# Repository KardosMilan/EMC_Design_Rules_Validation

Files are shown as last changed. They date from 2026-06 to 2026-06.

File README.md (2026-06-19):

# Automotive SEPIC Converter — EMC Design Rules Validation

> **Complete engineering workflow for an automotive-grade SEPIC DC-DC converter, from power-stage dimensioning through iterative EMC filter development to laboratory validation.**

---

## Overview

This project documents the full development and validation cycle of a switching power supply designed to meet demanding automotive EMC requirements. Starting from topology selection and component dimensioning, the work progresses through multiple hardware revisions, EMC-oriented filter design, and systematic laboratory validation — including electrical, frequency-domain, and thermal measurements.

Two contrasting PCB design iterations (SEPIC-A2 and SEPIC-B) are included side by side, demonstrating the measurable EMC impact of layout and filter decisions.

## Example of a designed PCB in aluminium housing

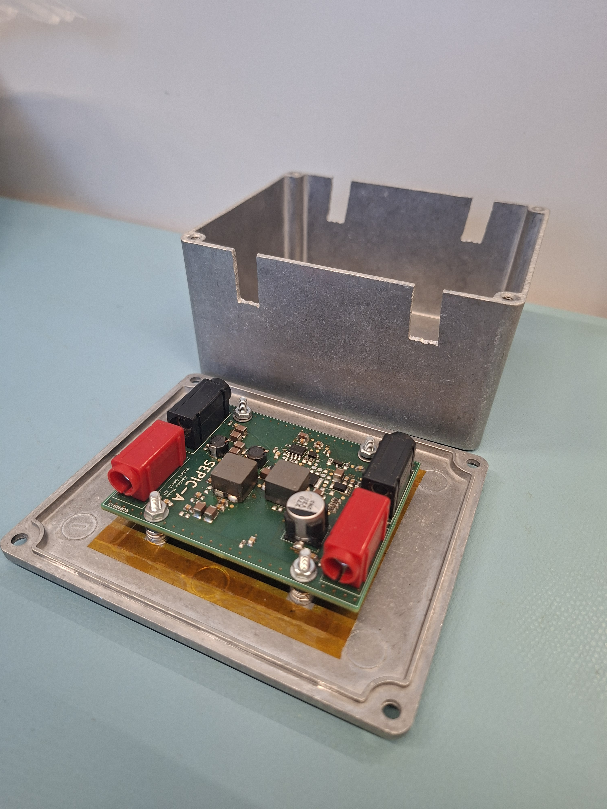
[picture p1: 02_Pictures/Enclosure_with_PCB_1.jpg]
Enclosure with PCB


---

## Project Goals

- Design an automotive SEPIC converter power stage with appropriate switching-frequency selection and thermal management
- Identify and characterise conducted and radiated emission sources
- Develop and iteratively optimise LC input/output EMC filters
- Validate all design decisions through laboratory measurements
- Correlate theoretical calculations with experimental results
- Produce a documented engineering process suitable for future design iterations

---

## Engineering Workflow

### 1 — System Design
Component selection, power-stage dimensioning, switching-frequency optimisation, thermal considerations, and initial PCB layout preparation.

### 2 — EMC Filter Development
LC filter calculations, topology comparison, resonance analysis, and iterative optimisation verified against laboratory measurements. All calculation sheets are included in the repository.

### 3 — Prototype Manufacturing
Custom PCB design with microcontroller integration, automotive-grade components, and dedicated measurement interfaces. Two hardware revisions are provided:

| Revision | Design Intent |
|---|---|
| **SEPIC-A2** | Reference iteration — poor EMC layout (emission source example) |
| **SEPIC-B**  | Optimised iteration — improved EMC layout and filter (target design) |

### 4 — Measurement & Validation

| Domain | Method |
|---|---|
| Electrical  | Switching waveform analysis, frequency-domain characterisation, noise quantification |
| EMC | Conducted emission measurement, filter effectiveness comparison between revisions |
| Thermal | FLIR thermal imaging, hotspot identification, thermal performance validation |
| Correlation | Calculated vs. measured comparison across all key parameters |

---

## Repository Structure

```
EMC_Design_Rules_Validation/
├── 01_Documents/
│   ├── Filter design documentation
│   ├── Measurement plans
│   ├── Correlation calculations
│   ├── Thermal analysis results
│   └── Oscilloscope captures
│
├── 02_Pictures/
│   ├── Prototype photos
│   └── Laboratory setup
│
├── 03_Calculations/
│   ├── Design calculations
│   ├── EMC filter calculations
│   └── Validation worksheets
│
├── 04_SEPIC_microcontroller_prototype/
│   ├── Prototype hardware
│   ├── Embedded controller integration
│   └── Supporting component libraries
│
└── 05_HW_design/
    ├── SEPIC-A2/     ← bad EMC design example
    ├── SEPIC-B/      ← optimised EMC design example
    └── PCB design resources
```

---

## Technology Stack

| Area | Tools & Methods |
|---|---|
| PCB Design | CAD schematic & layout tools |
| Calculations | Excel-based engineering worksheets |
| Electrical Measurement | Oscilloscope (time & frequency domain)  |
| Thermal Measurement | FLIR thermal camera |
| EMC Measurement | Conducted emission laboratory equipment |
| Embedded Platform | Automotive-grade microcontroller |

---

## Key Outcomes

- Designed and validated two SEPIC converter hardware revisions with measurably different EMC behaviour
- Developed EMC filter solutions grounded in both analytical calculation and experimental iteration
- Demonstrated a systematic correlation methodology between design predictions and laboratory results
- Produced a complete, reproducible engineering workflow applicable to future power electronics and EMC projects

---

## Author

**Kardos Milan**  
Electrical / Electronics Engineer  
*Specialising in Power Electronics, EMC Validation, Hardware Design, and Embedded Systems*

---

## License

This repository is shared for portfolio and reference purposes. All rights reserved.

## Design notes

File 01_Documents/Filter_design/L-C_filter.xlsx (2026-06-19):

Power supply input impedance |  |  | fi | s_i | Z_i
 |  |  | 0 | 0 | 23.87826319
V_in | 40 | V | 1 | 0.5711986643 | 28445.95364
I_out | 1 | A | 2 | 12.56637061 | 2550600.543
V_out | 5 | V | 3 | 18.84955592 | 276482.7453
 |  |  | 4 | 25.13274123 | 5410530.956
Output inductor |  |  |  | 0 | 23.87826319
L_out | 66 | uH |  | 0 | 23.87826319
 |  |  |  | 0 | 23.87826319
DC resistance |  |  |  | 0 | 23.87826319
R_L | 0.0088 | Ohm |  | 9 | 863306.2534
 |  |  |  | 10 | 93938.80675
Output capacitor |  |  |  | 11 | 18134.86307
C_out | 68 | uF |  | 12 | 3941.037132
ESR_C_out | 0.09 | Ohm |  | 13 | 2651674.45
 |  |  |  | 14 | 2885210.735
Duty Cycle | 0.458 | - |  | 15 | 3119283.552
 |  |  |  | 16 | 3353804.378
Output Impedance |  |  |  | 17 | 3588703.15
R_out | 5 | Ohm |  | 18
f_i | 100 | Hz |  | 19
w_i | 628 |  |  | 20
s_i | 3945.840373 |  |  | 21
Z_i |  |  |  | 22
 |  |  |  | 23
 |  |  |  | 24
 |  |  |  | 25
 |  |  |  | 26
 |  |  |  | 27
 |  |  |  | 28
 |  |  |  | 29
 |  |  |  | 30
 |  |  |  | 31
Filter
L_f
C_f
R_d | #DIV/0!
C_d | 0
ESR_Cd
Z_3 | #DIV/0!
Z_2
Z_3-2 | #DIV/0!
F_2 | #DIV/0!
Z_f2
Z_1

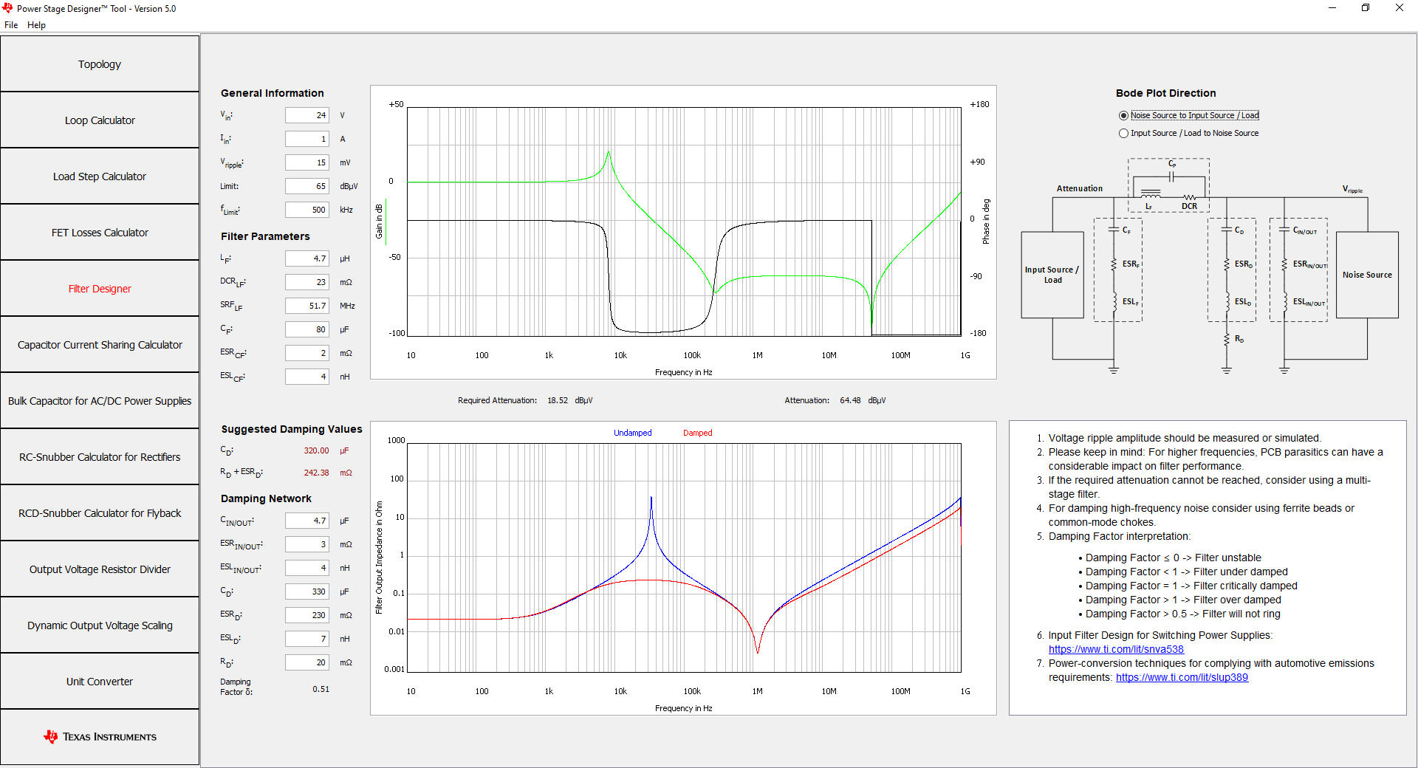
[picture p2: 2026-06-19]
01_Documents/Filter_design/Final_Filter3.png

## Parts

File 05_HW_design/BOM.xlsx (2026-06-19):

Reference | Value | Shop | Datasheet | Footprint | Qty | Bolti Darab | Ár (ft) | Összesen |  | 4db PCB-re [db] | Összesen [ft]
R5 | 1.1k | https://hu.farnell.com/panasonic/erj6geyj112v/res-1k1-5-0-125w-0805-thick-film/dp/2323808 | http://industrial.panasonic.com/cdbs/www-data/pdf/RDA0000/AOA0000C301.pdf | Resistor_SMD:R_0805_2012Metric_Pad1.20x1.40mm_HandSolder | 1 | 10 | 14.7 | 147 |  | 4 | 147
R4 | 1R | https://hu.farnell.com/bourns/cr0805-j-1r0elf/res-1r-5-0-125w-0805-thick-film/dp/2333534 | https://www.farnell.com/datasheets/3693949.pdf | Resistor_SMD:R_0805_2012Metric_Pad1.20x1.40mm_HandSolder | 1 | 10 | 3.6 | 36 |  | 4 | 36
R28 | R | https://hu.farnell.com/walsin/wr12x151-jtl/res-150r-5-0-25w-1206-thick-film/dp/2671138 | https://4donline.ihs.com/images/VipMasterIC/IC/WATC/WATC-S-A0005256878/WATC-S-A0005256878-1.pdf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 | Resistor_SMD:R_1206_3216Metric_Pad1.30x1.75mm_HandSolder | 1 | 10 | 5.571 | 55.71 |  | 4 | 55.71
C31 | 1uF, 25V | https://hu.farnell.com/avx/08053g105zat2a/cap-1-f-25v-y5v-0805/dp/2332746 | https://4donline.ihs.com/images/VipMasterIC/IC/AVXC/AVXC-S-A0011272541/AVXC-S-A0011272541-1.pdf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 | Capacitor_SMD:C_0805_2012Metric_Pad1.18x1.45mm_HandSolder | 1 | 10 | 42.88 | 428.8 |  | 4 | 428.8
C32 | 680pF, 100V | https://hu.farnell.com/avx/06031c681kat2a/cap-680pf-100v-mlcc-0603/dp/3288880 | https://4donline.ihs.com/images/VipMasterIC/IC/AVXC/AVXC-S-A0013335498/AVXC-S-A0014059611-1.pdf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 | Capacitor_SMD:C_0603_1608Metric_Pad1.08x0.95mm_HandSolder | 1 | 10 | 18 | 180 |  | 4 | 180
C5,C6,C7,C8,C9,C14,C15,C16,C17,C18,C20,C42 | 10uF, 50V | https://hu.farnell.com/tdk/cga6p3x7s1h106k250ab/cap-10-f-50v-10-x7s-1210/dp/2211159 | https://www.farnell.com/datasheets/3816851.pdf | Capacitor_SMD:C_1210_3225Metric_Pad1.33x2.70mm_HandSolder | 12 | 12 | 244.47 | 2933.64 |  | 48 | 11734.56
C4,C10,C11,C12,C13,C19,C41 | 100nF, 50V | https://hu.farnell.com/kemet/c0805x104j5rac3316/cap-0-1-f-50v-5-x7r-0805/dp/2666904 | https://4donline.ihs.com/images/VipMasterIC/IC/KEME/KEME-S-A0018777717/KEME-S-A0018891838-1.pdf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 | Capacitor_SMD:C_0805_2012Metric_Pad1.18x1.45mm_HandSolder | 7 | 10 | 293 | 2930 |  | 28 | 8204
C1,C2,C3,C21,C23,C37,C38,C46 | 1nF, 100V | https://hu.farnell.com/kemet/c0805x102k1racauto/cap-1000pf-100v-10-x7r-0805/dp/2821055 | https://4donline.ihs.com/images/VipMasterIC/IC/KEME/KEME-S-A0018892237/KEME-S-A0018892237-1.pdf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 | Capacitor_SMD:C_0805_2012Metric_Pad1.18x1.45mm_HandSolder | 8 | 10 | 84 | 840 |  | 32 | 2688
C47 | 2.2uF, 50V | https://hu.farnell.com/kemet/c1206c225m5ractu/cap-2-2-f-50v-20-x7r-1206/dp/2820946 | https://search.kemet.com/component-documentation/download/specsheet/C1206C225M5RACTU | Capacitor_SMD:C_1206_3216Metric_Pad1.33x1.80mm_HandSolder | 1 | 10 | 89 | 890 |  | 4 | 890
C22 | 470pF, 50V | https://hu.farnell.com/kemet/c0603s471k5racauto/cap-mlcc-aec-q200-470pf-50v-0603/dp/2904848 | https://4donline.ihs.com/images/VipMasterIC/IC/KEME/KEME-S-A0018897373/KEME-S-A0018902451-1.pdf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 | Capacitor_SMD:C_0603_1608Metric_Pad1.08x0.95mm_HandSolder | 1 | 10 | 75 | 750 |  | 4 | 750
C30 | 100pF, 50V | https://hu.farnell.com/kemet/c0402c101k5gacauto/cap-100pf-50v-10-c0g-np0-0402/dp/2904514 | https://4donline.ihs.com/images/VipMasterIC/IC/KEME/KEME-S-A0018897402/KEME-S-A0018897402-1.pdf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 | Capacitor_SMD:C_0402_1005Metric_Pad0.74x0.62mm_HandSolder | 1 | 10 | 14 | 140 |  | 4 | 140
C29 | 1nF, 50V | https://hu.farnell.com/kemet/c0402c102j5racauto/cap-1000pf-50v-5-x7r-0402/dp/2904523 | https://4donline.ihs.com/images/VipMasterIC/IC/KEME/KEME-S-A0018897413/KEME-S-A0018897413-1.pdf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 | Capacitor_SMD:C_0402_1005Metric | 1 | 10 | 16 | 160 |  | 4 | 160
C34,C35,C36,C43 | 4.7nF, 100V | https://hu.farnell.com/kemet/c0805c472k1ractu/cap-4700pf-100v-10-x7r-0805/dp/2332407 | https://4donline.ihs.com/images/VipMasterIC/IC/KEME/KEME-S-A0018902345/KEME-S-A0018902501-1.pdf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 | Capacitor_SMD:C_0805_2012Metric_Pad1.18x1.45mm_HandSolder | 4 | 10 | 57 | 570 |  | 16 | 912
D1,D2 | PMEG6030ELP | https://hu.farnell.com/nexperia/pmeg6030elpx/schottky-rect-3a-60v-sod128/dp/2498564 | https://4donline.ihs.com/images/VipMasterIC/IC/NEXP/NEXP-S-A0003105620/NEXP-S-A0003105670-1.pdf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 | Diode_SMD:D_SOD-128 | 2 | 5 | 192 | 960 |  | 8 | 1536
U2 | SZBZX84C4V7ET1G | https://hu.farnell.com/on-semiconductor/szbzx84c4v7et1g/zener-diode-aecq101-4-7v-0-25w/dp/3368153 | https://4donline.ihs.com/images/VipMasterIC/IC/ONSM/ONSM-S-A0004900107/ONSM-S-A0002809067-1.pdf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 | Package_TO_SOT_SMD:SOT-23 | 1 | 5 | 98.5 | 492.5 |  | 4 | 492.5
R9 | 5.62k | https://hu.farnell.com/panasonic/erj2rkf5621x/res-5k62-1-0-1w-0402-thick-film/dp/2302714 | https://4donline.ihs.com/images/VipMasterIC/IC/PANA/PANA-S-A0007945459/PANA-S-A0007945459-1.pdf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 | Resistor_SMD:R_0402_1005Metric_Pad0.72x0.64mm_HandSolder | 1 | 10 | 10.5 | 105 |  | 4 | 105
R6,R18,R19,R26 | 22R | https://hu.farnell.com/multicomp-pro/mp000064/res-aec-q200-22r-5-0-25w-0805/dp/3127834 | https://4donline.ihs.com/images/VipMasterIC/IC/SCMP/SCMP-S-A0008596024/SCMP-S-A0008596024-1.pdf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 | Resistor_SMD:R_0805_2012Metric_Pad1.20x1.40mm_HandSolder | 4 | 10 | 23.44 | 234.4 |  | 16 | 375.04
R23 | 0.05R | https://hu.farnell.com/multicomp-pro/mclrp12jtdrr050/res-detec-corriente-0r05-5-3w/dp/2828309 | https://4donline.ihs.com/images/VipMasterIC/IC/SCMP/SCMP-S-A0011506898/SCMP-S-A0011506898-1.pdf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 | Resistor_SMD:R_2512_6332Metric_Pad1.40x3.35mm_HandSolder | 6 | 10 | 133.4 | 1334 |  | 24 | 3201.6
Q1 | BUK9Y25-60E_A004X | https://hu.farnell.com/nexperia/buk9y25-60e-115/mosfet-aecq101-n-ch-60v-34a-lfpak56/dp/3439716 | https://assets.nexperia.com/documents/data-sheet/BUK9Y25-60E.pdf | KiCad1:BUK9Y2560EA004X | 1 | 1 | 345 | 345 |  | 4 | 1380
D3 | PMEG6020ELR | https://hu.farnell.com/nexperia/pmeg6020elrx/rectifier-schottky-2a-60v-sod/dp/2469682 | https://assets.nexperia.com/documents/data-sheet/PMEG6020ELR.pdf | Diode_SMD:Nexperia_CFP3_SOD-123W | 1 | 5 | 187.9 | 939.5 |  | 4 | 939.5
C26 | 270 uF, 35V | https://at.farnell.com/en-AT/epcos/b40900b7277m000/cap-270uf-35v-alu-elec-hybrid/dp/3266927 | https://product.tdk.com/system/files/dam/doc/product/capacitor/aluminum-electrolytic/hybrid-polymer/data_sheet/20/30/db/aec/b40900.pdf | Capacitor_SMD:CP_Elec_10x10.5 | 1 | Itthon nem elérhet? csak 1000 darabos |  |  | euroban lehet csak | 4
C40 | 330pF, 100V | https://hu.farnell.com/kemet/c0402c331j1gactu/cap-330pf-100v-mlcc-0402/dp/2940861 | https://search.kemet.com/component-documentation/download/specsheet/C0402C331J1GACTU | Capacitor_SMD:C_0402_1005Metric_Pad0.74x0.62mm_HandSolder | 1 | 10 | 29.3 | 293 |  | 4 | 293
C44 | 47nF, 16V | https://hu.farnell.com/yageo/cc0402krx7r7bb472/cap-4700pf-16v-10-x7r-0402/dp/3019251 | https://www.yageo.com/upload/media/product/productsearch/datasheet/mlcc/UPY-GPHC_X7R_6.3V-to-50V_20.pdf | Capacitor_SMD:C_0402_1005Metric_Pad0.74x0.62mm_HandSolder | 1 | 10 | 5.7 | 57 |  | 4 | 57
C25 | 100nF, 50V | https://hu.farnell.com/kemet/c0805x104j5rac3316/cap-0-1-f-50v-5-x7r-0805/dp/2666904 | https://search.kemet.com/component-documentation/download/specsheet/C0805X104J5RAC3316 | Capacitor_SMD:C_0805_2012Metric_Pad1.18x1.45mm_HandSolder | 1 | 10 | 293.3 | 2933 |  | 4 | 2933
C39 | 4.7nF, 50V | https://hu.farnell.com/kemet/c1206c475k5pactu/cap-4-7-f-50v-10-x5r-1206/dp/1572637 | https://search.kemet.com/component-documentation/download/specsheet/C0805X104J5RAC3316 | Capacitor_SMD:C_1206_3216Metric_Pad1.33x1.80mm_HandSolder | 1 | 10 | 85.3 | 853 |  | 4 | 853
L3,L4 | VCSC108T-150MS6K | https://www.digikey.de/de/products/detail/delta-electronics-cyntec/VCSC108T-150MS6K/22581627 | https://www.cyntec.com/upfile/products/download/(A8)%20VCSC108T%20MS6K%20Series_standard.pdf | Inductor_SMD:VCSC108T | 2 | 2 | 900 | 1800 | euroban lehet csak | 8
L1,L2 | 4.7uH | https://hu.farnell.com/tdk/clf6045t-4r7n-d/inductor-4-7uh-2-5a-30-pwr-100khz/dp/2362560 | https://www.farnell.com/datasheets/1763485.pdf | KiCad5:CLF6045__ | 2 | Ithon csak 1000 darabos |  |  |  | 8
R25 | 5.11k | https://hu.farnell.com/walsin/wr08x5111ftl/res-5k11-1-0-125w-0805-thick-film/dp/2671054 | https://4donline.ihs.com/images/VipMasterIC/IC/WATC/WATC-S-A0005256878/WATC-S-A0005256878-1.pdf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 | Resistor_SMD:R_0805_2012Metric_Pad1.20x1.40mm_HandSolder | 1 | 10 | 10 | 100 |  | 4 | 100
R11,R12,R21,R22 | 2.2R | https://hu.farnell.com/te-connectivity/crgcq0603j2r2/res-2r2-5-0603-thick-film/dp/2861848 | https://www.farnell.com/datasheets/2609223.pdf | Resistor_SMD:R_0201_0603Metric_Pad0.64x0.40mm_HandSolder | 4 | 10 | 5.17 | 51.7 |  | 16 | 82.72
R7 | 15k | https://hu.farnell.com/multicomp/mcmr04x153-jtl/res-15k-5-0-0625w-0402-ceramic/dp/2072651 | https://www.farnell.com/datasheets/2860635.pdf | Resistor_SMD:R_0402_1005Metric_Pad0.72x0.64mm_HandSolder | 1 | 10 | 2.8 | 28 |  | 4 | 28
R8 | 46.4k | https://hu.farnell.com/multicomp-pro/mcwf08w4642btl/res-46k4-0-1-0-125w-0805-thin/dp/2338193 | https://www.farnell.com/datasheets/2863884.pdf | Resistor_SMD:R_0805_2012Metric_Pad1.20x1.40mm_HandSolder | 1 | 10 | 121.4 | 1214 |  | 4 | 1214
J1 | Banana_Red_IN | https://hu.farnell.com/multicomp/24-243-1/banana-socket-20a-4mm-pcb-red/dp/1698982?pf_custSiteRedirect=true | https://www.farnell.com/datasheets/2963540.pdf | banana_red:242431 | 1 | 1 | 319 | 319 |  | 4 | 1276
J2 | Banana_Red_OUT | https://hu.farnell.com/multicomp/24-243-1/banana-socket-20a-4mm-pcb-red/dp/1698982?pf_custSiteRedirect=true | https://www.farnell.com/datasheets/2963540.pdf | banana_red:242431 | 1 | 1 | 319 | 319 |  | 4 | 1276
J3 | Banana_Black_IN | https://hu.farnell.com/multicomp/24-243-2/receptacle-20a-4mm-pcb-solder/dp/1698983?pf_custSiteRedirect=true | https://www.farnell.com/datasheets/2963540.pdf | banana_black:242432 | 1 | 1 | 319 | 319 |  | 4 | 1276
J4 | Banana_Black_OUT | https://hu.farnell.com/multicomp/24-243-2/receptacle-20a-4mm-pcb-solder/dp/1698983?pf_custSiteRedirect=true | https://www.farnell.com/datasheets/2963540.pdf | banana_black:242432 | 1 | 1 | 319 | 319 |  | 4 | 1276
R1,R2,R3 | 21.5R | https://hu.farnell.com/te-connectivity/rp73pf2a21r5btdf/res-21r5-0-1-0-25w-0805-thin-film/dp/2116983 | https://www.farnell.com/datasheets/3156821.pdf | Resistor_SMD:R_0805_2012Metric_Pad1.20x1.40mm_HandSolder | 3 | 3 | 113 | 339 |  | 12 | 1356
R17 | 5.11R | https://hu.farnell.com/yageo/rc0805fr-075r11l/res-5r11-1-0-125w-0805-thick-film/dp/3496079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 | https://www.farnell.com/datasheets/3795017.pdf | Capacitor_SMD:C_0805_2012Metric_Pad1.18x1.45mm_HandSolder | 1 | 10 | 11 | 110 |  | 4 | 110
C24 | 10uF, 50V | https://hu.farnell.com/tdk/cga6p3x7s1h106k250ab/cap-10-f-50v-10-x7s-1210/dp/2211159 | https://www.farnell.com/datasheets/3816851.pdf | Capacitor_SMD:C_1210_3225Metric_Pad1.33x2.70mm_HandSolder | 1 | 1 | 244 | 244 |  | 4 | 976
C27,C28 | 2.2uF, 50V | https://hu.farnell.com/tdk/c3216x7r1h225k160ae/cap-2-2-f-50v-10-x7r-1206/dp/2906842 | https://www.farnell.com/datasheets/3919271.pdf | Capacitor_SMD:C_1206_3216Metric_Pad1.33x1.80mm_HandSolder | 2 | 5 | 163 | 815 |  | 8 | 1304
R10 | 3.01k | https://hu.farnell.com/koa-speer-electronics/rk73h1ettp3011f/res-3k01-1-0-1w-0402/dp/3538958 | https://www.koaglobal.com/-/media/Files/KOA_Global/EN/product/commonpdf/rk73h.pdf | Resistor_SMD:R_0402_1005Metric_Pad0.72x0.64mm_HandSolder | 1 | 10 | 6 | 60 |  | 4 | 60
IC1 | NCV898031D1R2G | https://hu.farnell.com/on-semiconductor/ncv898031d1r2g/dc-dc-controllers/dp/3613065 | https://www.onsemi.com/pub/Collateral/NCV898031-D.PDF?hkey=EF798316E3902B6ED9A73243A3159BB0 | KiCad4:SOIC127P600X175-8N | 1 | 2500 dbos szalag |  |  |  | 4
C33 | 6.8nF, 100V | https://hu.farnell.com/wurth-elektronik/885012206113/cap-6800pf-100v-10-x7r-0603/dp/2812367 | https://www.we-online.com/components/products/datasheet/885012206113.pdf | Capacitor_SMD:C_0603_1608Metric_Pad1.08x0.95mm_HandSolder | 1 | 10 | 10.4 | 104 |  | 4 | 104
R24 | 10k | https://hu.farnell.com/yageo/rt0805brb0710kl/res-10k-0-1-0-125w-0805-thin-film/dp/3496710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 | https://www.yageo.com/upload/media/product/app/datasheet/rchip/pyu-rt_1-to-0.01_rohs_l.pdf | Resistor_SMD:R_0805_2012Metric_Pad1.20x1.40mm_HandSolder | 1 | 10 | 135 | 1350 |  | 4 | 1350
 |  |  |  |  |  | Összesen: |  | 26099.25 |  |  | 50280.43
Housing | 4628 | https://hu.farnell.com/hammond/1590ce/enclosure-diecast/dp/1877076 | https://www.farnell.com/datasheets/1913809.pdf | .
 |  | EURO/DB | DB | össz
PCB rendelés | 73200 | 183 | 4 | 292800
 | https://www.eurocircuits.hu/pcb-beultetes-standard-pool/
 | https://be.eurocircuits.com/shop/assembly/configurator.aspx?sessionid=cbd32a67-34b7-461b-924a-d88c2fe45909 |  |  |  |  | Végösszeg | 347708.43

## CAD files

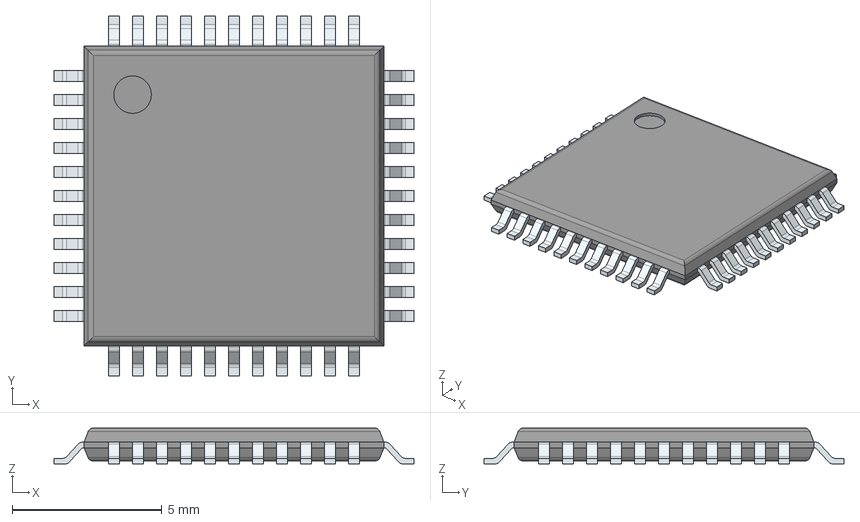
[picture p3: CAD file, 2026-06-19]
04_SEPIC_microcontroller_prototype/MYLIB/LIB_ATMEGA32U4-AU/ATMEGA32U4-AU/3D/ATMEGA32U4-AU.stp
12.0 x 12.0 x 1.20 mm
PinsArrayLR
PinsArrayTB

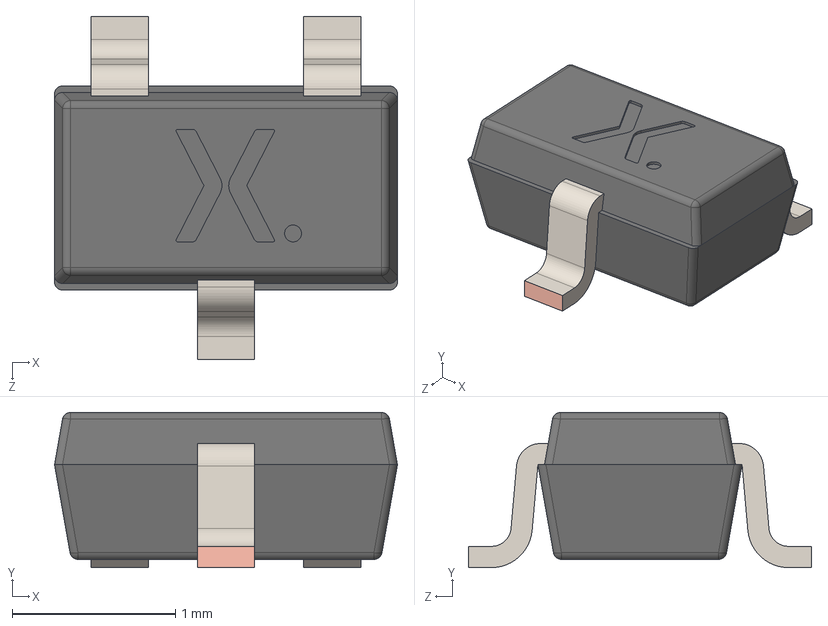
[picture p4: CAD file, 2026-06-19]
04_SEPIC_microcontroller_prototype/MYLIB/LIB_BC846BW,115/BC846BW,115/3D/BC846BW,115.stp
2.10 x 0.95 x 2.10 mm
Upper body
lower body
Lead x 3

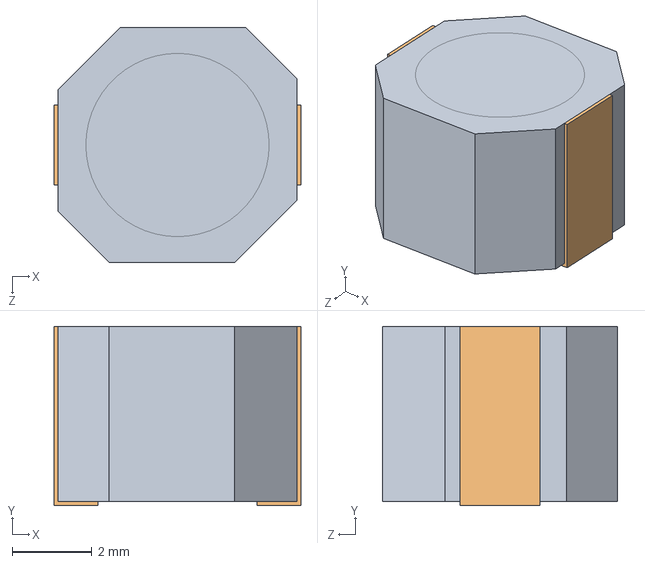
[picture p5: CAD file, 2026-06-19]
04_SEPIC_microcontroller_prototype/MYLIB/LIB_CLF6045T-4R7N-D/CLF6045T-4R7N-D/3D/CLF6045T-4R7N-D.stp
6.20 x 4.50 x 5.90 mm
CLF6045素体
CLF6045端子 x 2

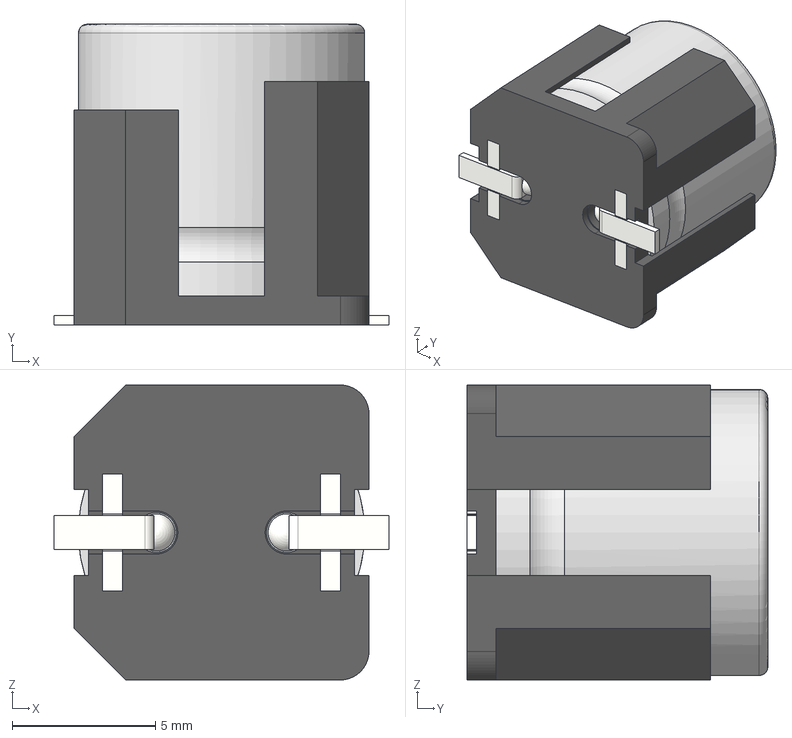
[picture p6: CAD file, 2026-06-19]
04_SEPIC_microcontroller_prototype/MYLIB/LIB_EEHZC1V271V/EEHZC1V271V/3D/EEHZC1V271V.stp
11.7 x 10.5 x 10.3 mm
ケースΦ10x9.5L SIDE CODE G
耐振品座版Φ10 SIZE CODE G
耐振品座版用補助端子Φ10 SIZE CODE G x 2
耐振品リード線Φ10 SIZE CODE G x 2

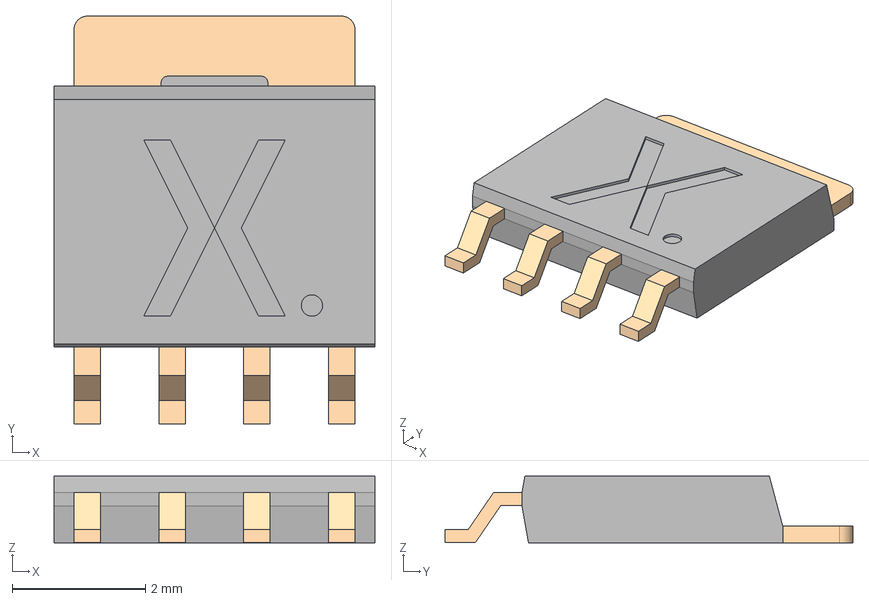
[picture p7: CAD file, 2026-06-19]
04_SEPIC_microcontroller_prototype/MYLIB/LIB_PHPT60415NYX/PHPT60415NYX/3D/PHPT60415NYX.stp
4.81 x 6.11 x 0.998 mm

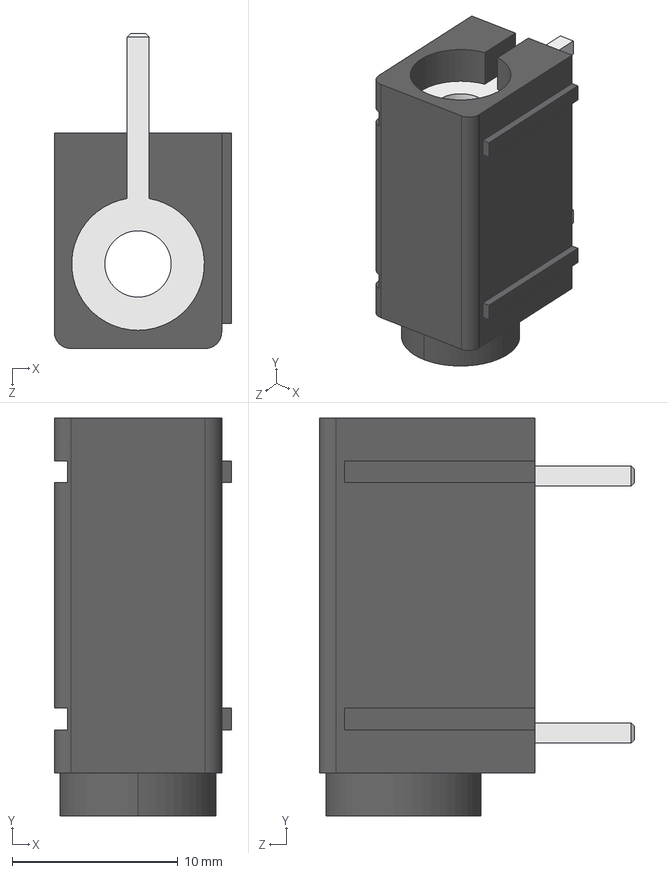
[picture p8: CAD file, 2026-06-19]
05_HW_design/SEPIC-A2/MYLIB/LIB_24.243.Black/24.243.2/3D/24.243.2.stp
10.7 x 24.0 x 19.0 mm

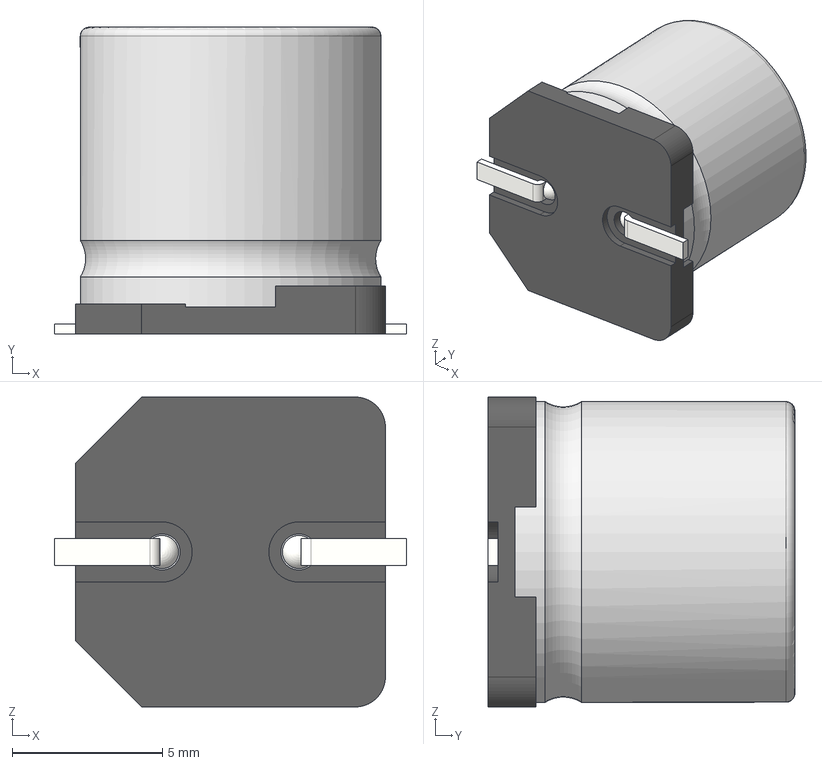
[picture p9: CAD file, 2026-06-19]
05_HW_design/SEPIC-B/MYLIB/LIB_EEEFT1H331GP/EEEFT1H331GP/3D/EEEFT1H331GP.stp
11.7 x 10.2 x 10.3 mm
標準品ケースΦ10x9.3L SIDE CODE G
標準品座版Φ10 SIZE CODE G
標準品リード線Φ10 SIZE CODE G改 x 2

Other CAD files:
05_HW_design/SEPIC-A2/MYLIB/LIB_24.243.Red/24.243.1/3D/24.243.1.stp
05_HW_design/SEPIC-B/MYLIB/LIB_24.243.Red/24.243.1/3D/24.243.1.stp
04_SEPIC_microcontroller_prototype/MYLIB/LIB_629105150521/629105150521/3D/629105150521.stp
04_SEPIC_microcontroller_prototype/MYLIB/LIB_629105150521/629105150521/Allegro/629105150521.psm
04_SEPIC_microcontroller_prototype/MYLIB/LIB_629105150521/629105150521/DEHDL/629105150521/chips/chips.prt
04_SEPIC_microcontroller_prototype/MYLIB/LIB_ATMEGA32U4-AU/ATMEGA32U4-AU/Allegro/qfp80p1200x1200x120-44n.psm
04_SEPIC_microcontroller_prototype/MYLIB/LIB_ATMEGA32U4-AU/ATMEGA32U4-AU/DEHDL/atmega32u4_au/chips/chips.prt
04_SEPIC_microcontroller_prototype/MYLIB/LIB_BC846BW,115/BC846BW,115/Allegro/sot65p210x110-3n.psm
04_SEPIC_microcontroller_prototype/MYLIB/LIB_BC846BW,115/BC846BW,115/DEHDL/bc846bw_115/chips/chips.prt
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

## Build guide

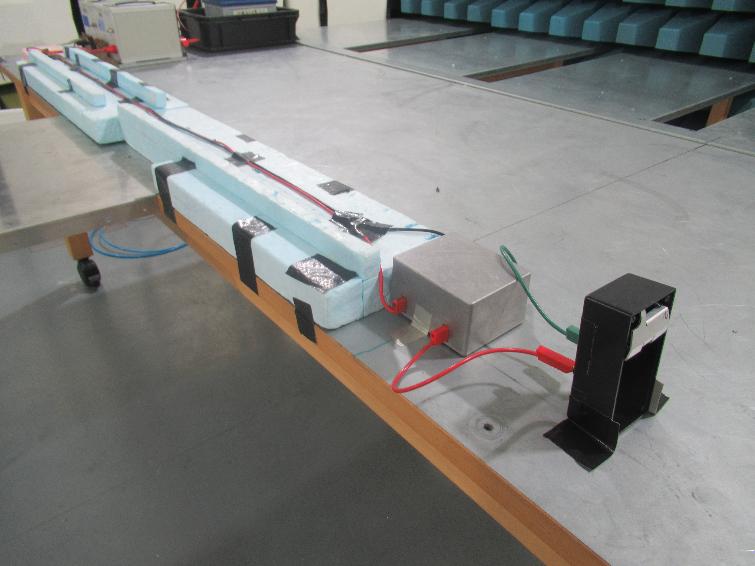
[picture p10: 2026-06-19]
01_Documents/MEASUREMENTS/REA_measurement_setup/IMG_0643.JPG

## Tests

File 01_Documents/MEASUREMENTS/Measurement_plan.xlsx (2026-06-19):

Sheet: REA
Mode | NH | No housing |  |  | követelmény? | CEV csütörtök
 | HO | Housing |  |  | 30MHz alatt RBW 9kHz |  |  | 13,5 V | 5 Amperes áramkorlát
 | GH | Grounded housing |  |  | felette 120kHz
 |  |  |  |  | illetve Average és peak detector a teljes sávban egy-két sávban pedig QP detektor még érdekes lehet po AM és FM sáv
MAKE PICTURES!!!
Meas. Number | SETUP | DUT | Mode | Polarization | Frequency | Antenna | Status
01 | Setup 1 | SEPIC-A | NH | V | 9 kHz-30 MHz | Monopole | Done
02 | Setup 1 | SEPIC-A | NH | H | 30 MHz - 1GHz | Bilog | Done
03 | Setup 1 | SEPIC-A | NH | V | 30 MHz - 1GHz | Bilog | Done
04 | Setup 1 | SEPIC-A | HO | V | 9 kHz-30 MHz | Monopole | Done
05 | Setup 1 | SEPIC-A | HO | H | 30 MHz - 1GHz | Bilog | Done
06 | Setup 1 | SEPIC-A | HO | V | 30 MHz - 1GHz | Bilog | Done
07 | Setup 1 | SEPIC-A | GH | V | 9 kHz-30 MHz | Monopole | Done
08 | Setup 1 | SEPIC-A | GH | H | 30 MHz - 1GHz | Bilog | Done | 102 | Horiz
09 | Setup 1 | SEPIC-A | GH | V | 30 MHz - 1GHz | Bilog | Done | 103 | Vertical
10 | Setup 1 | SEPIC-B | NH | V | 9 kHz-30 MHz | Monopole | Done
11 | Setup 1 | SEPIC-B | NH | H | 30 MHz - 1GHz | Bilog | Done
12 | Setup 1 | SEPIC-B | NH | V | 30 MHz - 1GHz | Bilog | Done
13 | Setup 1 | SEPIC-B | HO | V | 9 kHz-30 MHz | Monopole | Done
14 | Setup 1 | SEPIC-B | HO | H | 30 MHz - 1GHz | Bilog | Done
15 | Setup 1 | SEPIC-B | HO | V | 30 MHz - 1GHz | Bilog | Done
16 | Setup 1 | SEPIC-B | GH | V | 9 kHz-30 MHz | Monopole | Done
17 | Setup 1 | SEPIC-B | GH | H | 30 MHz - 1GHz | Bilog | Done
18 | Setup 1 | SEPIC-B | GH | V | 30 MHz - 1GHz | Bilog | Done
19 | Setup 2 | SEPIC-A | NH | V | 9 kHz-30 MHz | Monopole | Done
20 | Setup 2 | SEPIC-A | NH | H | 30 MHz - 1GHz | Bilog | Done
21 | Setup 2 | SEPIC-A | NH | V | 30 MHz - 1GHz | Bilog | Done
22 | Setup 2 | SEPIC-A | HO | V | 9 kHz-30 MHz | Monopole | Done
23 | Setup 2 | SEPIC-A | HO | H | 30 MHz - 1GHz | Bilog | Done
24 | Setup 2 | SEPIC-A | HO | V | 30 MHz - 1GHz | Bilog | Done
25 | Setup 2 | SEPIC-A | GH | V | 9 kHz-30 MHz | Monopole | Done
26 | Setup 2 | SEPIC-A | GH | H | 30 MHz - 1GHz | Bilog | Done | 100 | Ferrit bead | Horiz
27 | Setup 2 | SEPIC-A | GH | V | 30 MHz - 1GHz | Bilog | Done | 101 | Ferrit bead | Vertical
28 | Setup 2 | SEPIC-B | NH | V | 9 kHz-30 MHz | Monopole | Done
29 | Setup 2 | SEPIC-B | NH | H | 30 MHz - 1GHz | Bilog | Done
30 | Setup 2 | SEPIC-B | NH | V | 30 MHz - 1GHz | Bilog | Done
31 | Setup 2 | SEPIC-B | HO | V | 9 kHz-30 MHz | Monopole | Done
32 | Setup 2 | SEPIC-B | HO | H | 30 MHz - 1GHz | Bilog | Done
33 | Setup 2 | SEPIC-B | HO | V | 30 MHz - 1GHz | Bilog | Done
34 | Setup 2 | SEPIC-B | GH | V | 9 kHz-30 MHz | Monopole | Done
35 | Setup 2 | SEPIC-B | GH | H | 30 MHz - 1GHz | Bilog | Done
36 | Setup 2 | SEPIC-B | GH | V | 30 MHz - 1GHz | Bilog | Done

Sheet: CEV
Mode | NH | No housing |  |  | FFT vel mérjük
 | HO | Housing
 | GH | Grounded housing
MAKE PICTURES!!!
Meas. Number | SETUP | DUT | Mode | LISN Mode | Frequency | Status
01 | Setup 2 | SEPIC-A | NH | Plus | 100kHz-108MHz | Done
02 | Setup 2 | SEPIC-A | NH | Minus | 100kHz-108MHz | Done
03 | Setup 2 | SEPIC-A | NH | COM | 100kHz-108MHz | Done
04 | Setup 2 | SEPIC-A | NH | DIFF | 100kHz-108MHz | Done
05 | Setup 2 | SEPIC-A | HO | Plus | 100kHz-108MHz | Done | COM és Diff korrekció nélkül mérve
06 | Setup 2 | SEPIC-A | HO | Minus | 100kHz-108MHz | Done | Cispr 25 ed. 4- class 3
07 | Setup 2 | SEPIC-A | HO | COM | 100kHz-108MHz | Done | setup 25 cm
08 | Setup 2 | SEPIC-A | HO | DIFF | 100kHz-108MHz | Done
09 | Setup 2 | SEPIC-A | GH | Plus | 100kHz-108MHz | Done
10 | Setup 2 | SEPIC-A | GH | Minus | 100kHz-108MHz | Done
11 | Setup 2 | SEPIC-A | GH | COM | 100kHz-108MHz | Done
12 | Setup 2 | SEPIC-A | GH | DIFF | 100kHz-108MHz | Done
13 | Setup 2 | SEPIC-B | NH | Plus | 100kHz-108MHz | Done
14 | Setup 2 | SEPIC-B | NH | Minus | 100kHz-108MHz | Done
15 | Setup 2 | SEPIC-B | NH | COM | 100kHz-108MHz | Done
16 | Setup 2 | SEPIC-B | NH | DIFF | 100kHz-108MHz | Done
17 | Setup 2 | SEPIC-B | HO | Plus | 100kHz-108MHz | Done
18 | Setup 2 | SEPIC-B | HO | Minus | 100kHz-108MHz | Done
19 | Setup 2 | SEPIC-B | HO | COM | 100kHz-108MHz | Done
20 | Setup 2 | SEPIC-B | HO | DIFF | 100kHz-108MHz | Done
21 | Setup 2 | SEPIC-B | GH | Plus | 100kHz-108MHz | Done
22 | Setup 2 | SEPIC-B | GH | Minus | 100kHz-108MHz | Done
23 | Setup 2 | SEPIC-B | GH | COM | 100kHz-108MHz | Done
24 | Setup 2 | SEPIC-B | GH | DIFF | 100kHz-108MHz | Done

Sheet: BCI
Open loop | GH | HO | Target | 100 mA |  |  | DC coupling Ac coupling RMS
közös módus |  |  |  |  |  |  | Mekkor a fesz beesés %
5cm re monitor tekercs |  |  |  |  |  |  | setup 4
tekercs pozik | 15 | 75
Modul | CW | AM
PCB | 2
Level | iso11452-4 | level 4
freq | 100kHz-400Mhz |  |  |  |  |  | 10-200 közt 1 MHz
step size | 11452-1 | szerint |  |  |  |  | 200-400 közt 5 MHz
Dwell time min 2s
Meas. Number | SETUP | DUT | Mode | Modulation | Pozition | LEVEL | Frequency | Status | Achieved (Not Died)
01 | Setup 1 | SEPIC-A | GH | CW | 15 cm | 4,2,1 | 100kHz-400MHz | Done | lv. 2
02 | Setup 1 | SEPIC-A | GH | AM | 15 cm | 4.1 | 100kHz-400MHz | Done | lv. 4
03 | Setup 1 | SEPIC-A | GH | CW | 75 cm | 4,2,1 | 100kHz-400MHz | Done | lv. 1
04 | Setup 1 | SEPIC-A | GH | AM | 75 cm | 4.1 | 100kHz-400MHz | Done | lv. 4
05 | Setup 1 | SEPIC-A | HO | CW | 15 cm | 4.1 | 100kHz-400MHz | Done | lv. 4
06 | Setup 1 | SEPIC-A | HO | AM | 15 cm | 4.1 | 100kHz-400MHz | Done | lv.4
07 | Setup 1 | SEPIC-A | HO | CW | 75 cm | 4,2,1 | 100kHz-400MHz | Done | lv. 1
08 | Setup 1 | SEPIC-A | HO | AM | 75 cm | 4,2,1 | 100kHz-400MHz | Done | lv. 1
09 | Setup 1 | SEPIC-B | GH | CW | 15 cm | 4.1 | 100kHz-400MHz | Done | lv. 4
10 | Setup 1 | SEPIC-B | GH | AM | 15 cm | 4.1 | 100kHz-400MHz | Done | lv. 4
11 | Setup 1 | SEPIC-B | GH | CW | 75 cm | 4.1 | 100kHz-400MHz | Done | lv. 4
12 | Setup 1 | SEPIC-B | GH | AM | 75 cm | 4.1 | 100kHz-400MHz | Done | lv.4
13 | Setup 1 | SEPIC-B | HO | CW | 15 cm | 4.1 | 100kHz-400MHz | Done | lv. 4 | differential is | plusz
14 | Setup 1 | SEPIC-B | HO | AM | 15 cm | 4.1 | 100kHz-400MHz | Done | lv. 4
15 | Setup 1 | SEPIC-B | HO | CW | 75 cm | 4.1 | 100kHz-400MHz | Done | lv. 4 | differential is | plusz, mínusz
16 | Setup 1 | SEPIC-B | HO | AM | 75 cm | 4.1 | 100kHz-400MHz | Done | lv. 4

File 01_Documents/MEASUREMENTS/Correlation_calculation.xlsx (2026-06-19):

SEPIC-A | SEPIC_B | CEV data |  | Összesítve | CEV átlag [dBuV/m] | REA átlag [dBuV/m] | BCI átlag [dBuV/m] | REA data
16.2 (-53.8) | 13.5 (-56.5) | 16.2 | 13.5 | Sepic-A | 34.704 | 20.663 |  | -53.8 | -56.5
20.8 (-29.2) | 13.5 (-36.5) | 20.8 | 13.5 | Sepic-B | 30.058 | 17.839 |  | -29.2 | -36.5
53.1 (8.1) | 41.8 (-3.2) | 53.1 | 41.8 | Javulás A-hoz képest | 43.30508861% | 34.27746795% | #DIV/0! | 8.1 | -3.2
42.3 (6.3) | 26.8 (-9.2) | 42.3 | 26.8 |  |  |  |  | 6.3 | -9.2
41 (5) | 28.4 (-7.6) | 41 | 28.4 | Limittől | CEV átlag [dBuV/m] | REA átlag [dBuV/m] | BCI átlag [dBuV/m] | 5 | -7.6
36.1 (0.1) | 27.5 (-8.5) | 36.1 | 27.5 | Sepic-A | -6.921 | -12.643 |  | 0.1 | -8.5
30.7 (0.7) | 22.3 (-7.7) | 30.7 | 22.3 | Sepic-B | -12.308 | -18.399 |  | 0.7 | -7.7
30.7 (0.7) | 21.8 (-8.2) | 30.7 | 21.8 | Javulás A -hoz képest | 67.08748733% | 60.09806445% | #DIV/0! | 0.7 | -8.2
-7.7 (-77.7) | -2.8 (-72.8) | -7.7 | -2.8 |  |  |  |  | -77.7 | -72.8
12 (-38) | 9.9 (-40.1) | 12 | 9.9 |  |  |  |  | -38 | -40.1
36.9 (-8.1) | 41.5 (-3.5) | 36.9 | 41.5 |  |  |  |  | -8.1 | -3.5
43.9 (7.9) | 37.8 (1.8) | 43.9 | 37.8 |  |  |  |  | 7.9 | 1.8
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

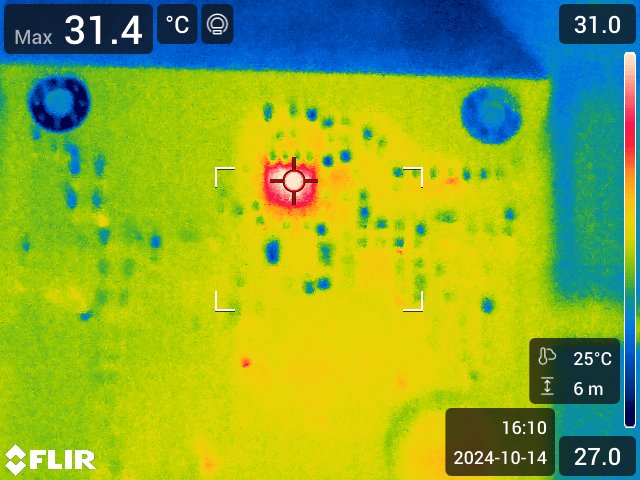
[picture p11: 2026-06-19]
01_Documents/MEASUREMENTS/FLIR_Thermal_Camera_Pictures/FLIR0271.jpg

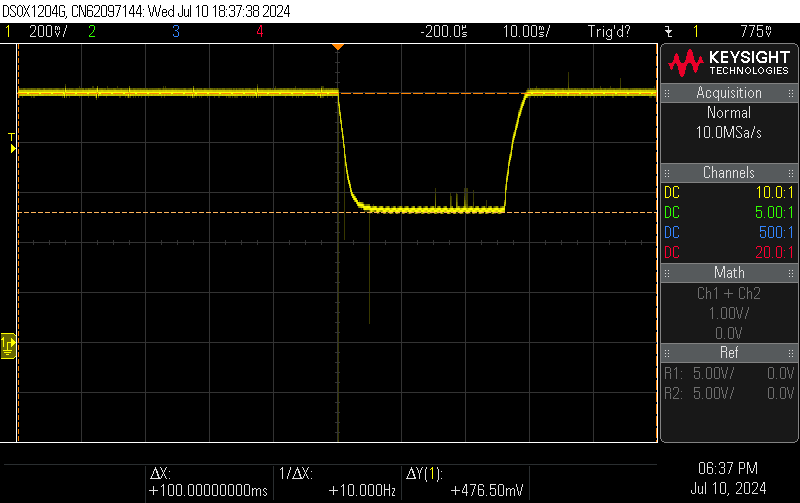
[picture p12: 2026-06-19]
01_Documents/MEASUREMENTS/Oscilloscope_Screenshots/scope_1.png

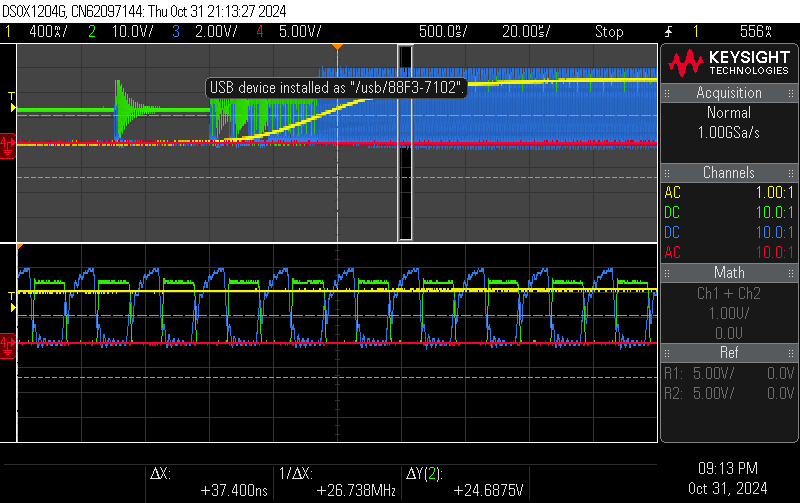
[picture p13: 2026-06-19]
01_Documents/MEASUREMENTS/Oscilloscope_Screenshots/scope_42.png

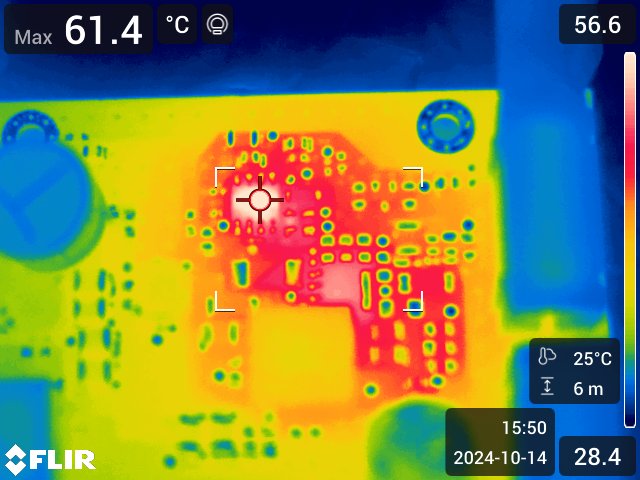
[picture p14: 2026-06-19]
01_Documents/MEASUREMENTS/FLIR_Thermal_Camera_Pictures/FLIR0267.jpg

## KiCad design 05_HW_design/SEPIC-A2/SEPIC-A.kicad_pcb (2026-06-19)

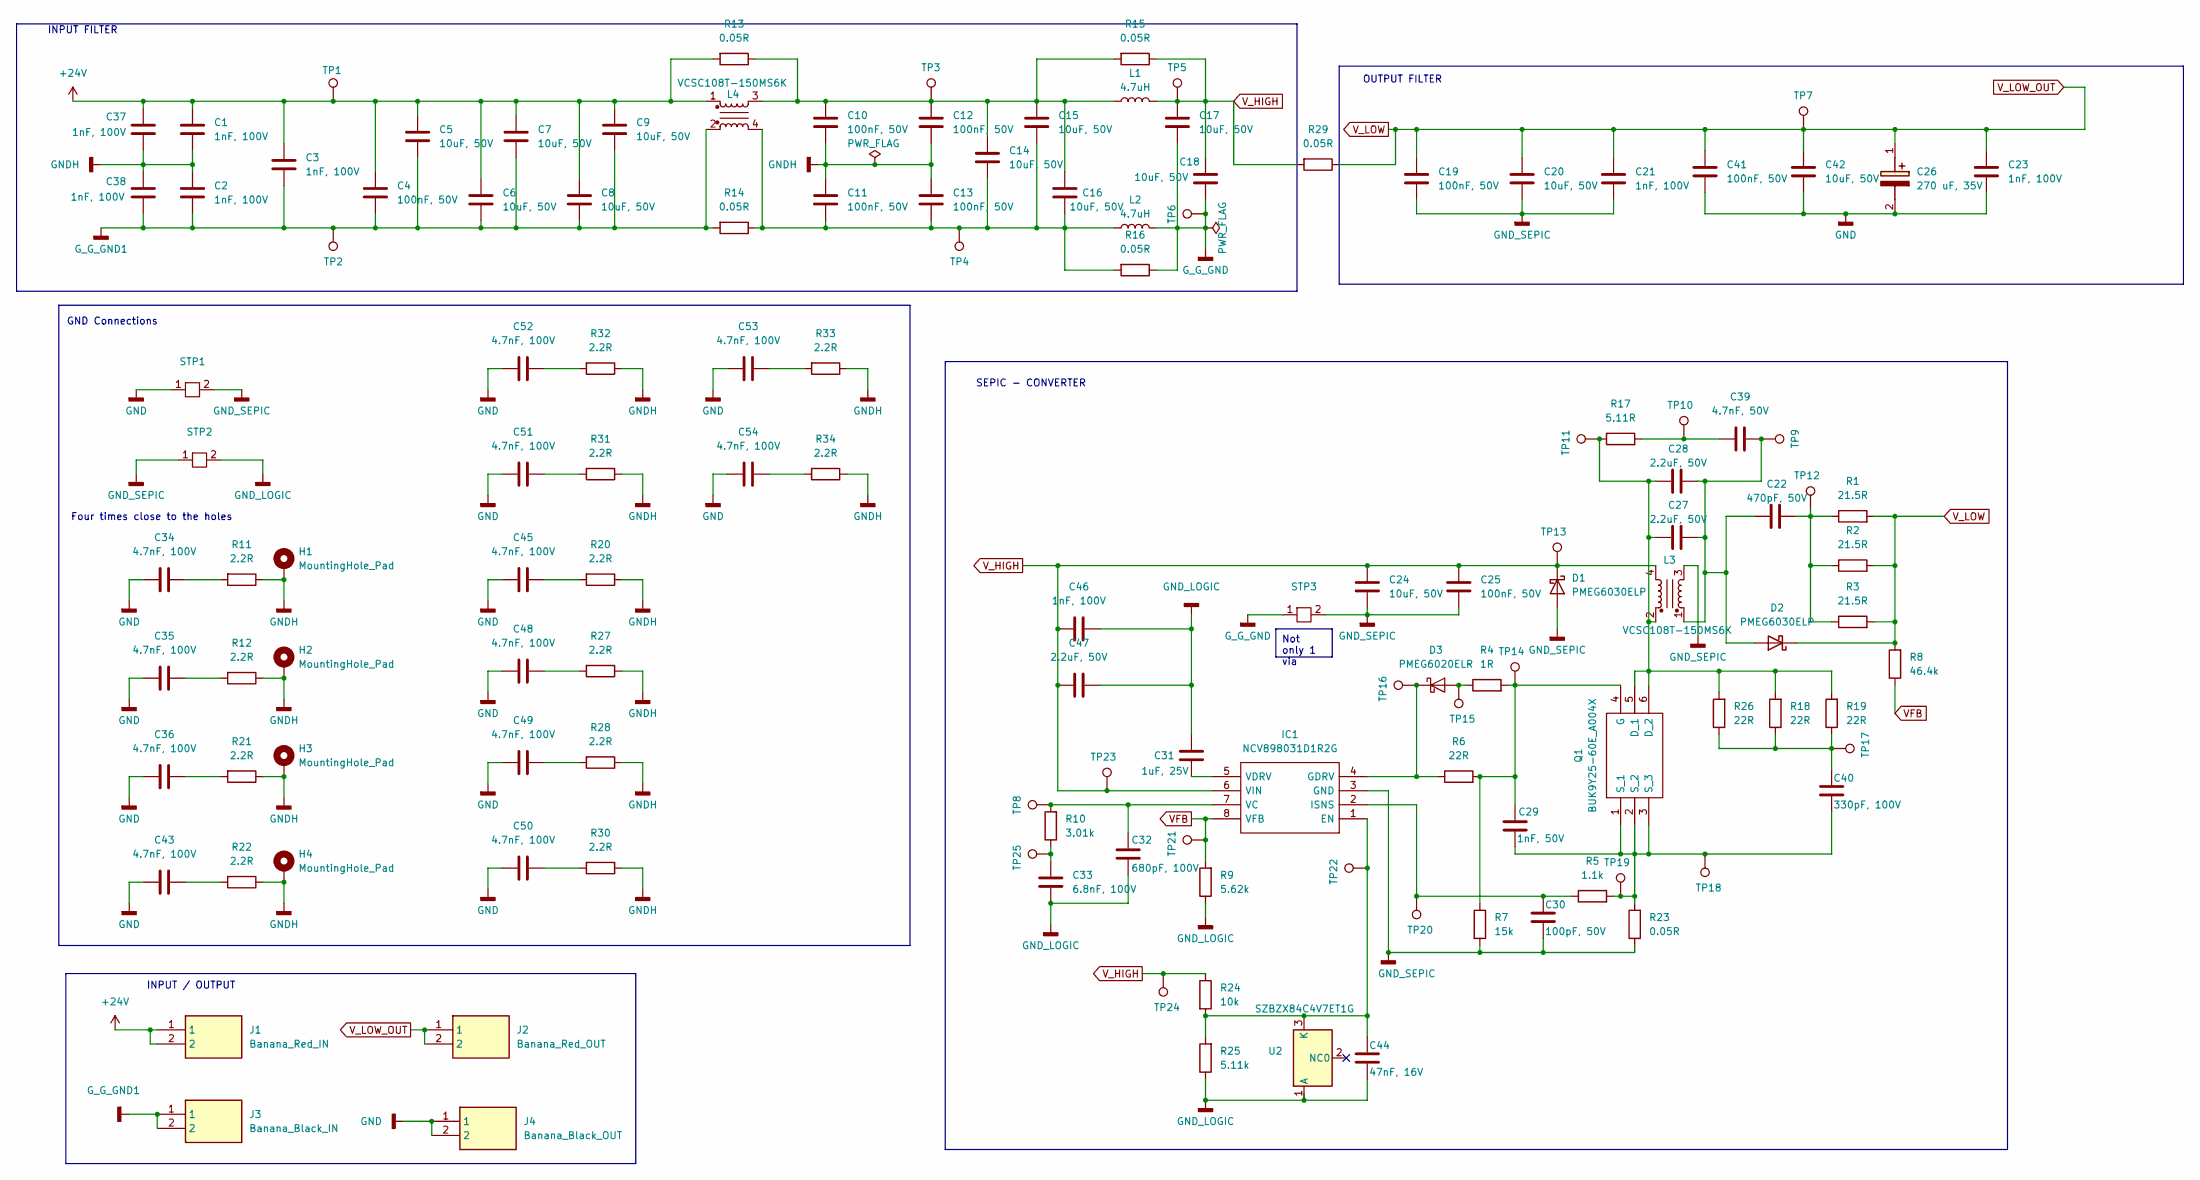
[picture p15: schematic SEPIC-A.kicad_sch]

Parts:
C1, C2, C3, C21, C23, C37, C38, C46: 1nF, 100V; C_0805_2012Metric_Pad1.18x1.45mm_HandSolder
C4, C10, C11, C12, C13, C19, C25, C41: 100nF, 50V; C_0805_2012Metric_Pad1.18x1.45mm_HandSolder
C5, C6, C7, C8, C9, C14, C15, C16, C17, C18, C20, C24, C42: 10uF, 50V; C_1210_3225Metric_Pad1.33x2.70mm_HandSolder
C22: 470pF, 50V; C_0603_1608Metric_Pad1.08x0.95mm_HandSolder
C26: 270 uF, 35V; CP_Elec_10x10.5; Manufacturer_Part_Number B40900B7277M000
C27, C28, C47: 2.2uF, 50V; C_1206_3216Metric_Pad1.33x1.80mm_HandSolder
C29: 1nF, 50V; C_0402_1005Metric
C30: 100pF, 50V; C_0402_1005Metric_Pad0.74x0.62mm_HandSolder
C31: 1uF, 25V; C_0805_2012Metric_Pad1.18x1.45mm_HandSolder
C32: 680pF, 100V; C_0603_1608Metric_Pad1.08x0.95mm_HandSolder
C33: 6.8nF, 100V; C_0603_1608Metric_Pad1.08x0.95mm_HandSolder
C34, C35, C36, C43, C45, C48, C49, C50, C51, C52, C53, C54: 4.7nF, 100V; C_0805_2012Metric_Pad1.18x1.45mm_HandSolder
C39: 4.7nF, 50V; C_1206_3216Metric_Pad1.33x1.80mm_HandSolder
C40: 330pF, 100V; C_0402_1005Metric_Pad0.74x0.62mm_HandSolder
C44: 47nF, 16V; C_0402_1005Metric_Pad0.74x0.62mm_HandSolder
D1, D2: PMEG6030ELP; D_SOD-128
D3: PMEG6020ELR; Nexperia_CFP3_SOD-123W
H1, H2, H3, H4: MountingHole_Pad; MountingHole_3.2mm_M3_Pad_Via
IC1: NCV898031D1R2G; SOIC127P600X175-8N; Manufacturer_Part_Number NCV898031D1R2G
J1: Banana_Red_IN; 242431; Manufacturer_Part_Number 24.243.1
J2: Banana_Red_OUT; 242431; Manufacturer_Part_Number 24.243.1
J3: Banana_Black_IN; 242432; Manufacturer_Part_Number 24.243.2
J4: Banana_Black_OUT; 242432; Manufacturer_Part_Number 24.243.2
L1, L2: 4.7uH; CLF6045__
L3, L4: VCSC108T-150MS6K; VCSC108T
Q1: BUK9Y25-60E_A004X; BUK9Y2560EA004X; Manufacturer_Part_Number BUK9Y25-60E/A004X
R1, R2, R3: 21.5R; R_0805_2012Metric_Pad1.20x1.40mm_HandSolder
R4: 1R; R_0805_2012Metric_Pad1.20x1.40mm_HandSolder
R5: 1.1k; R_0805_2012Metric_Pad1.20x1.40mm_HandSolder
R6, R18, R19, R26: 22R; R_0805_2012Metric_Pad1.20x1.40mm_HandSolder
R7: 15k; R_0402_1005Metric_Pad0.72x0.64mm_HandSolder
R8: 46.4k; R_0805_2012Metric_Pad1.20x1.40mm_HandSolder
R9: 5.62k; R_0402_1005Metric_Pad0.72x0.64mm_HandSolder
R10: 3.01k; R_0402_1005Metric_Pad0.72x0.64mm_HandSolder
R11, R12, R20, R21, R22, R27, R28, R30, R31, R32, R33, R34: 2.2R; R_0603_1608Metric_Pad0.98x0.95mm_HandSolder
R13, R14, R15, R16, R29: 0.05R; R_0805_2012Metric_Pad1.20x1.40mm_HandSolder
R17: 5.11R; C_0805_2012Metric_Pad1.18x1.45mm_HandSolder
R23: 0.05R; R_2512_6332Metric_Pad1.40x3.35mm_HandSolder
R24: 10k; R_0805_2012Metric_Pad1.20x1.40mm_HandSolder
R25: 5.11k; R_0805_2012Metric_Pad1.20x1.40mm_HandSolder
STP1, STP2, STP3: STP
TP1, TP2, TP3, TP4, TP5, TP6, TP7, TP8, TP9, TP10, TP11, TP12, TP13, TP14, TP15, TP16, TP17, TP18, TP19, TP20, TP21, TP22, TP23, TP24, TP25: TestPoint; TestPoint_Pad_D1.1mm
U2: SZBZX84C4V7ET1G; SOT-23

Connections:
+24V: C1.1, C3.1, C4.1, C5.1, C6.1, C7.1, C8.1, C9.1, C37.1, J1.1, J1.2, L4.1, R13.2, TP1.1
GND: C23.2, C26.2 (-), C34.1, C35.1, C36.1, C41.2, C42.2, C43.1, C45.1, C48.1, C49.1, C50.1, C51.1, C52.1, C53.1, C54.1, J4.1, J4.2, STP1.1
GNDH: C1.2, C2.1, C10.2, C11.1, C12.2, C13.1, C37.2, C38.1, H1.1, H2.1, H3.1, H4.1, R11.1, R12.1, R20.1, R21.1, R22.1, R27.1, R28.1, R30.1, R31.1, R32.1, R33.1, R34.1
GND_LOGIC: C31.1, C32.2, C33.2, C44.2, C46.2, C47.2, R9.1, R25.1, STP2.2, U2.1 (A)
GND_SEPIC: C19.2, C20.2, C21.2, C24.2, C25.2, C30.2, D1.2 (A), IC1.3 (GND), L3.3, R7.2, R23.1, STP1.2, STP2.1, STP3.2
G_G_GND: C17.2, C18.2, L2.2, R16.1, STP3.1, TP6.1
G_G_GND1: C2.2, C3.2, C4.2, C5.2, C6.2, C7.2, C8.2, C9.2, C38.2, J3.1, J3.2, L4.2, R14.2, TP2.1
unnamed: C10.1, C12.1, C14.1, C15.1, C16.1, L1.1, L4.3, R13.1, R15.2, TP3.1
unnamed: C11.2, C13.2, C14.2, C15.2, C16.2, L2.1, L4.4, R14.1, R16.2, TP4.1
unnamed: C22.2, R1.1, R2.1, R3.1, TP12.1
unnamed: C33.1, R10.1, TP25.1
unnamed: C34.2, R11.2
unnamed: C35.2, R12.2
unnamed: C36.2, R21.2
unnamed: C39.1, R17.2, TP10.1
unnamed: C40.1, R18.1, R19.1, R26.1, TP17.1
unnamed: C43.2, R22.2
unnamed: C45.2, R20.2
unnamed: C48.2, R27.2
unnamed: C49.2, R28.2
unnamed: C50.2, R30.2
unnamed: C51.2, R31.2
unnamed: C52.2, R32.2
unnamed: C53.2, R33.2
unnamed: C54.2, R34.2
unnamed: C22.1, C27.2, C28.2, C39.2, D2.2 (A), L3.1, TP9.1
unnamed: D3.2 (A), R4.1, TP15.1
unnamed: D3.1 (K), IC1.4 (GDRV), R6.1, TP16.1
unnamed: C44.1, IC1.1 (EN), R24.2, R25.2, TP22.1, U2.3 (K)
unnamed: C30.1, IC1.2 (ISNS), R5.1, TP20.1
unnamed: C32.1, IC1.7 (VC), R10.2, TP8.1
unnamed: C31.2, IC1.5 (VDRV)
unnamed: C27.1, C28.1, L3.2, Q1.5 (D_1), Q1.6 (D_2), R17.1, R18.2, R19.2, R26.2, TP11.1
unnamed: C29.1, Q1.4 (G), R4.2, R6.2, R7.1, TP14.1
unnamed: C29.2, C40.2, Q1.1 (S_1), Q1.2 (S_2), Q1.3 (S_3), R5.2, R23.2, TP18.1, TP19.1
VFB: IC1.8 (VFB), R8.1, R9.2, TP21.1
V_HIGH: C17.1, C18.1, C24.1, C25.1, C46.1, C47.1, D1.1 (K), IC1.6 (VIN), L1.2, L3.4, R15.1, R24.1, R29.2, TP5.1, TP13.1, TP23.1, TP24.1
V_LOW: C19.1, C20.1, C21.1, C23.1, C26.1 (+), C41.1, C42.1, D2.1 (K), J2.1, J2.2, R1.2, R2.2, R3.2, R8.2, R29.1, TP7.1

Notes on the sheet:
Not only 1 via
SEPIC - CONVERTER
GND Connections
INPUT FILTER
Four times close to the holes
INPUT / OUTPUT
OUTPUT FILTER

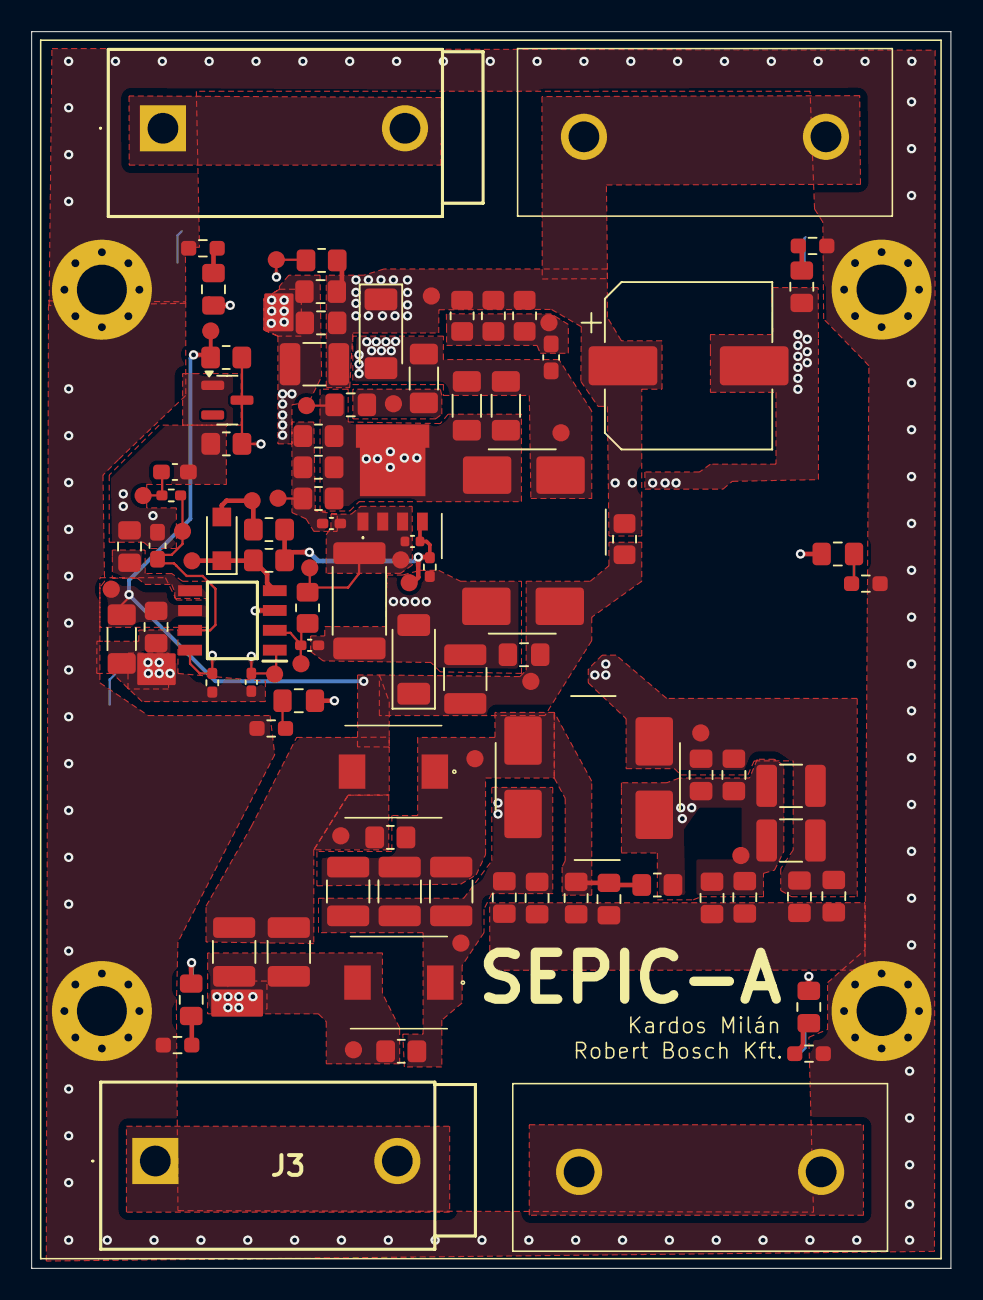
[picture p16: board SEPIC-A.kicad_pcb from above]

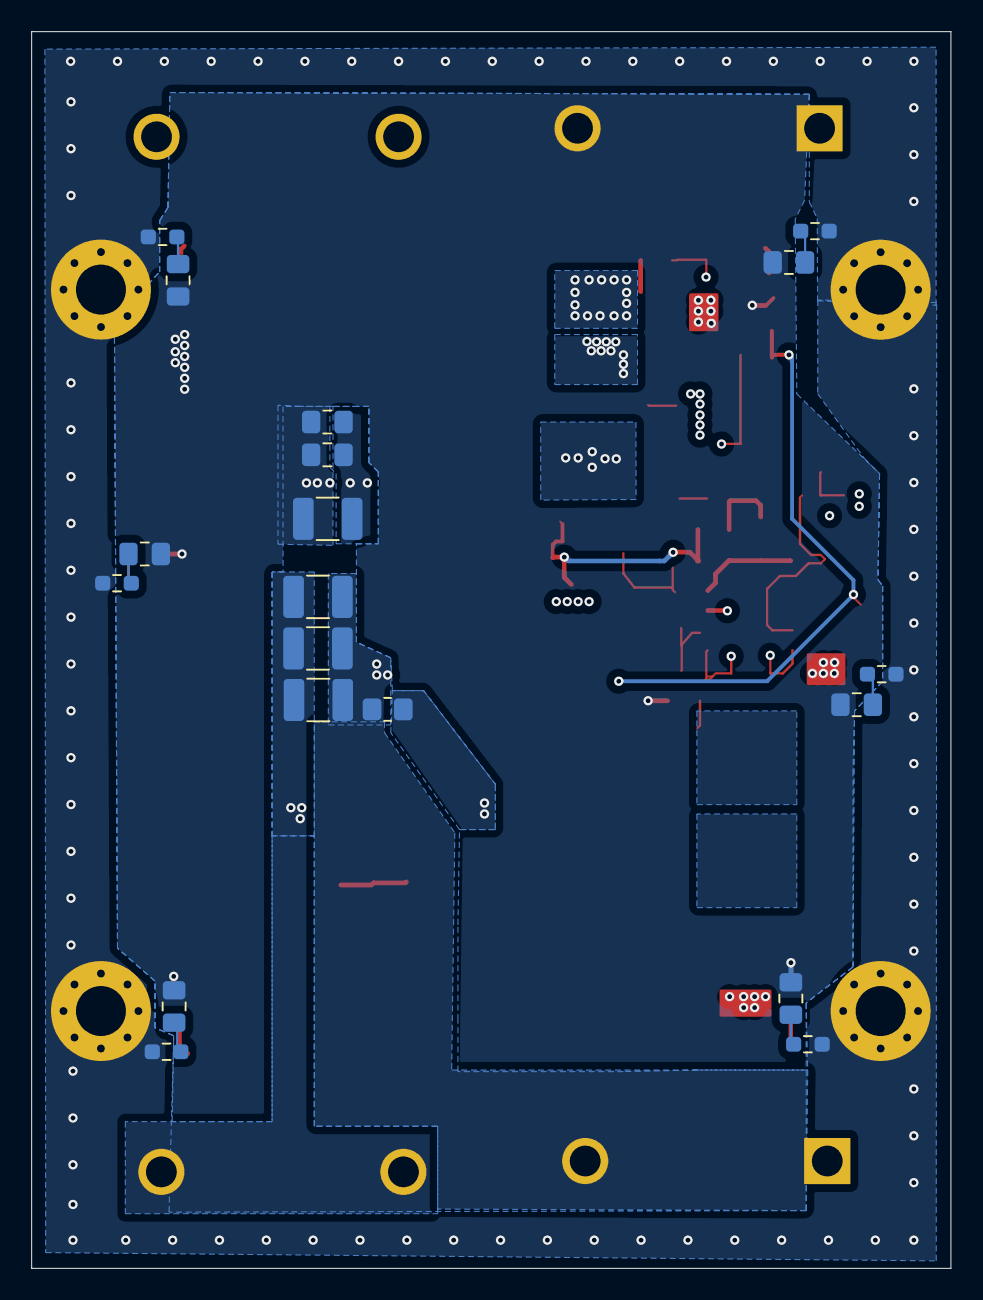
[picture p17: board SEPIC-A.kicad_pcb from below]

Board: 6 copper layers, 58.9 x 79.2 mm, 134 parts (19 on the bottom side), 38 nets.
